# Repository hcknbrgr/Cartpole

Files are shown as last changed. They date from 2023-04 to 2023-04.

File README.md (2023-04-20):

# Cart-pole Deep Q Network Reinforcement Learning
This is my attempt at utilizing a DQN to teach a robot to solve the cart-pole problem.

Original 3d models designed for a pole to be held upright on the cart and balance.  Upon completion of building the model, the wiring would keep the pole balanced on its own and did not allow for any balancing.  I pivoted, manually recreated the model to train to self-balance on its bottom two wheels.

Short video demonstrating the early attempts at training the model:
https://www.youtube.com/watch?v=-TPxhqB77YM

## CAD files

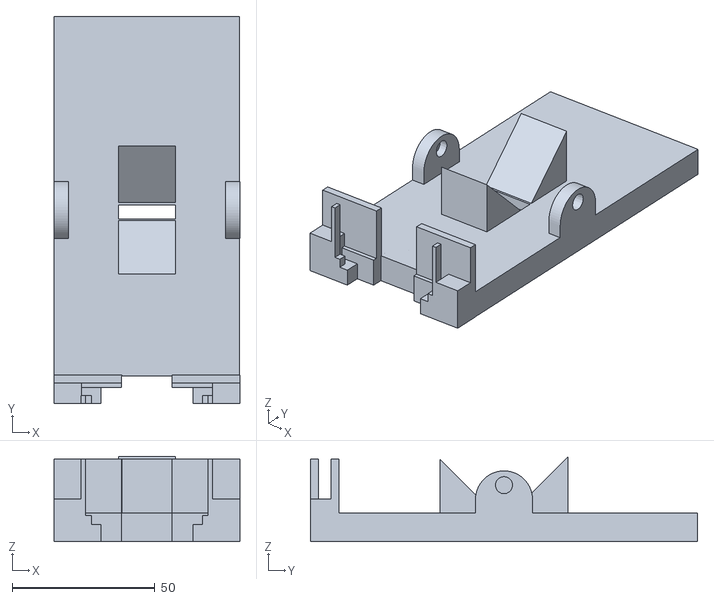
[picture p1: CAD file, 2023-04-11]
3dModels/FullCart0.4 TinkerCAD glitch fix.stl
65.1 x 135.6 x 29.9

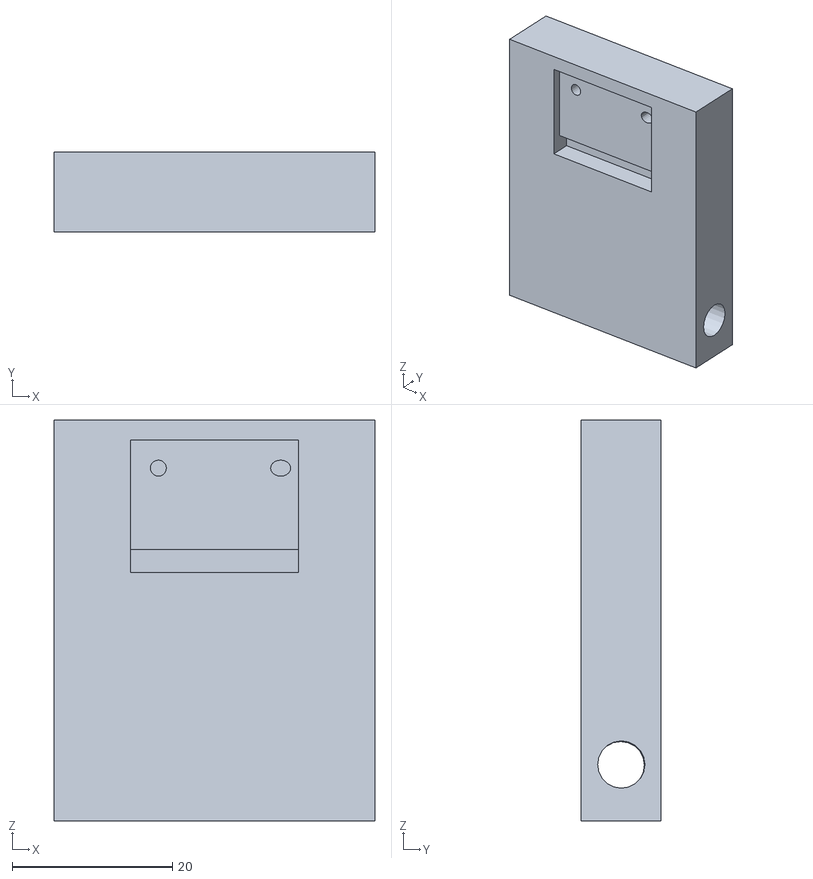
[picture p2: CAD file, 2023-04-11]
3dModels/Pole0.3.stl
40.0 x 10.0 x 50.0

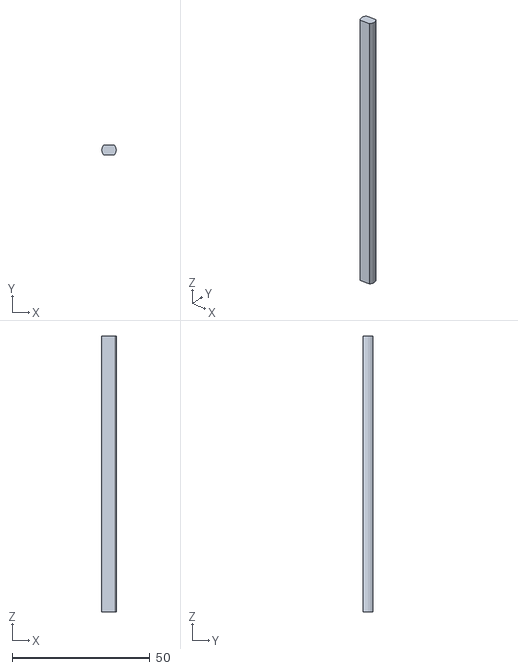
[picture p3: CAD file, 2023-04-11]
3dModels/Axel0.2.stl
5.30 x 3.50 x 100.0

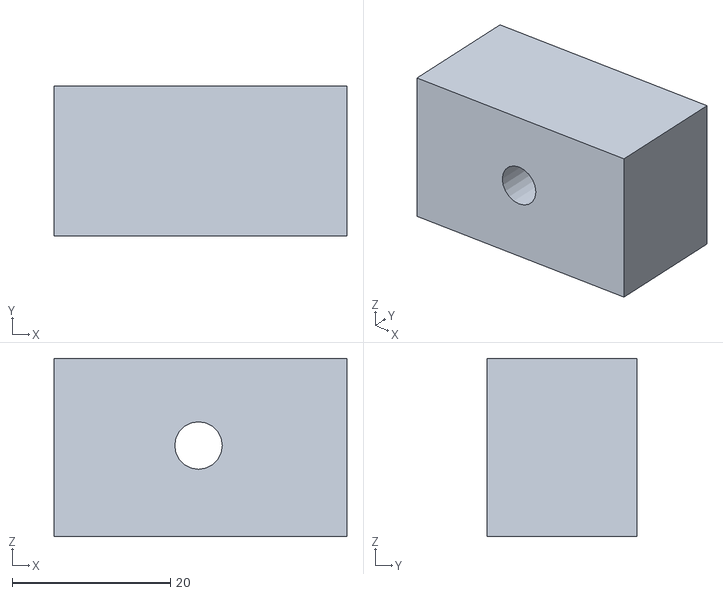
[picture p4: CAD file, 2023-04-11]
3dModels/Wheel Mounts0.2.stl
37.0 x 19.0 x 22.5

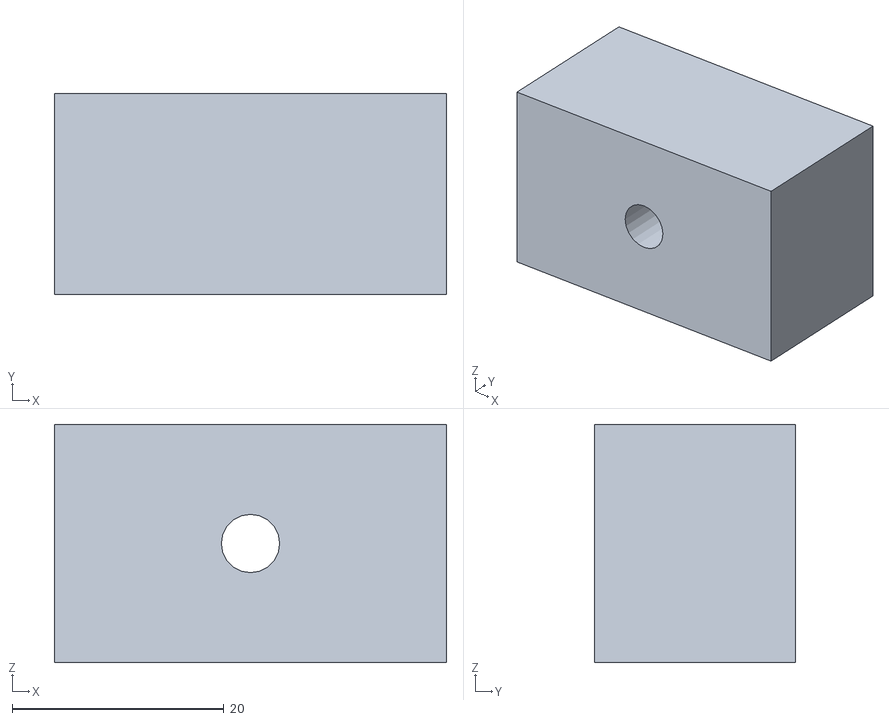
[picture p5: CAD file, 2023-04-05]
3dModels/Wheel Mounts0.1.stl
37.0 x 19.0 x 22.5

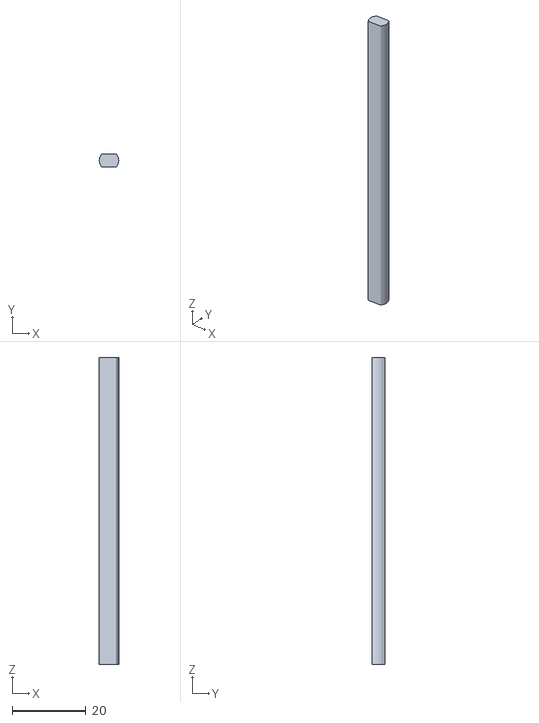
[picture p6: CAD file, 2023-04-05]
3dModels/Axel0.1.stl
5.30 x 3.50 x 83.0

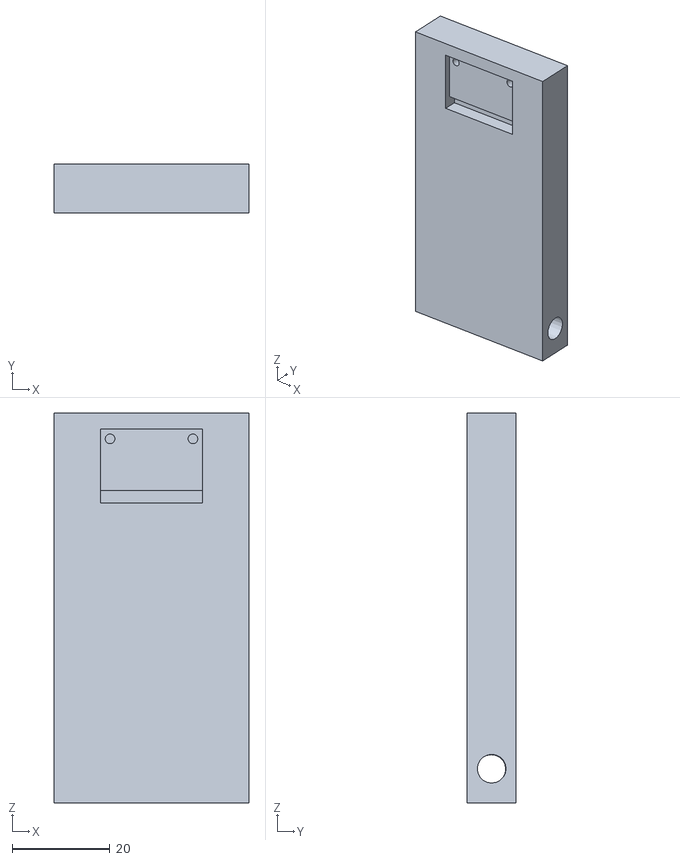
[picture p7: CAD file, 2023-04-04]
3dModels/Pole0.2.stl
40.0 x 10.0 x 80.0

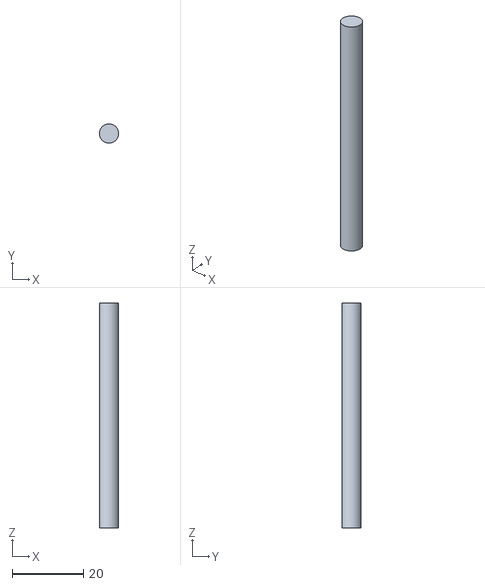
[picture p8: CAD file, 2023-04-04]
3dModels/Stick0.1.stl
5.40 x 5.40 x 63.0

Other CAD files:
3dModels/FullCart0.3.stl
3dModels/FullCart0.2.stl
3dModels/FullCart0.1.stl
3dModels/Pole0.1.stl

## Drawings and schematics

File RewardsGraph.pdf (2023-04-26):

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

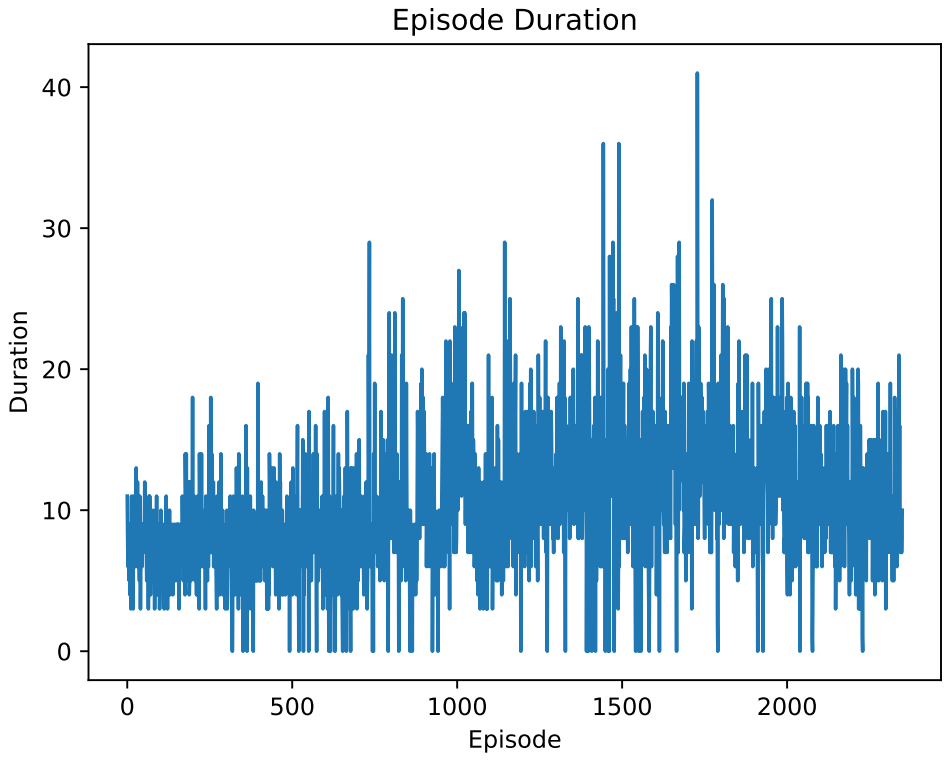
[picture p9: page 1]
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

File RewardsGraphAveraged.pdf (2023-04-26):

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

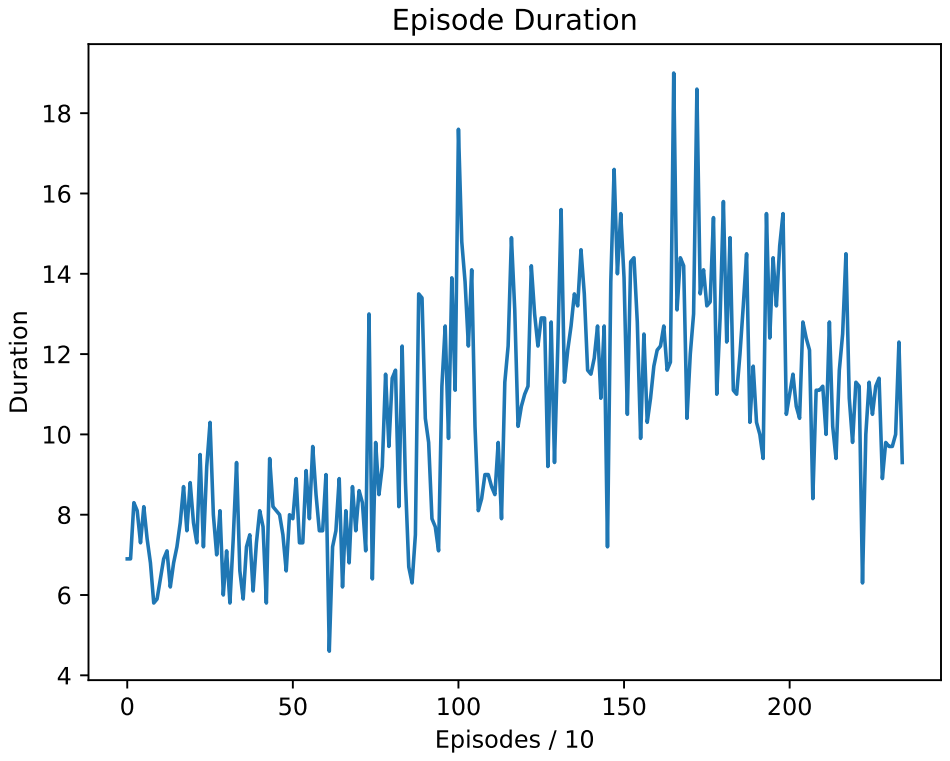
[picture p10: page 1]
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

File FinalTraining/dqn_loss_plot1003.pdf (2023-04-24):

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

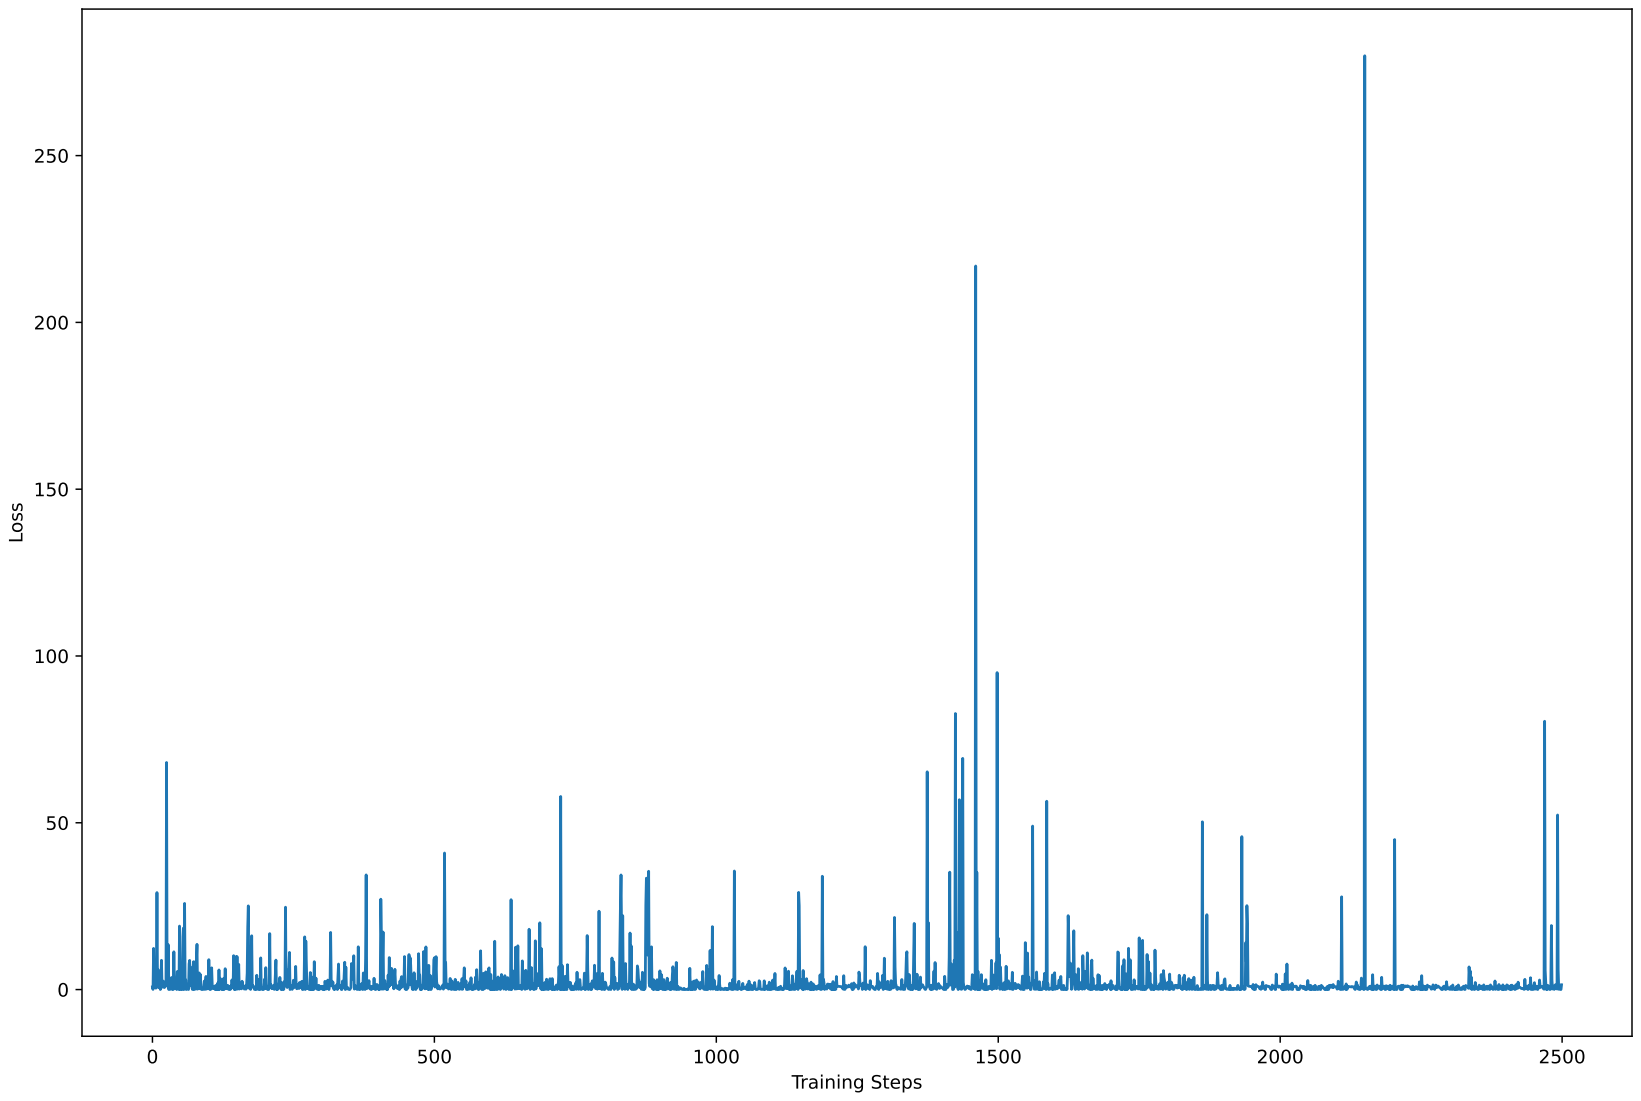
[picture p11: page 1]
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

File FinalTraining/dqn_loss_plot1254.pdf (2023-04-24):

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

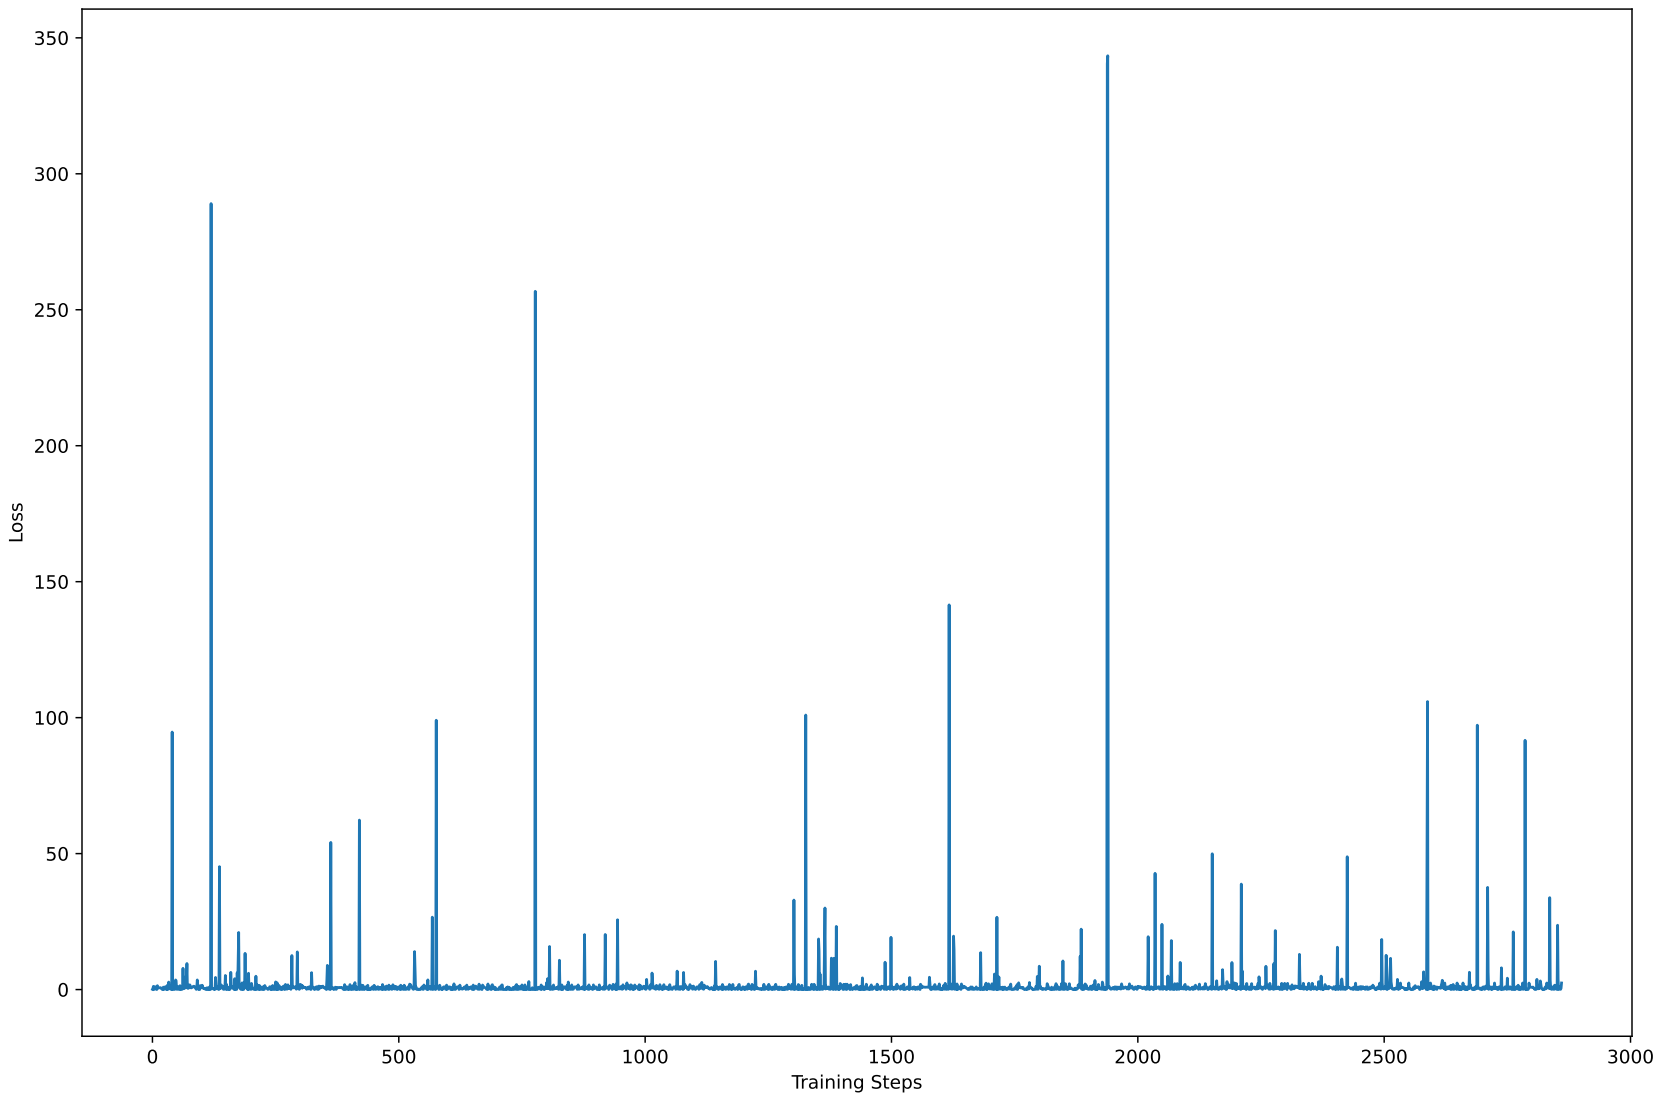
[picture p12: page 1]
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

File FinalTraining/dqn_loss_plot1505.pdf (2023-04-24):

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

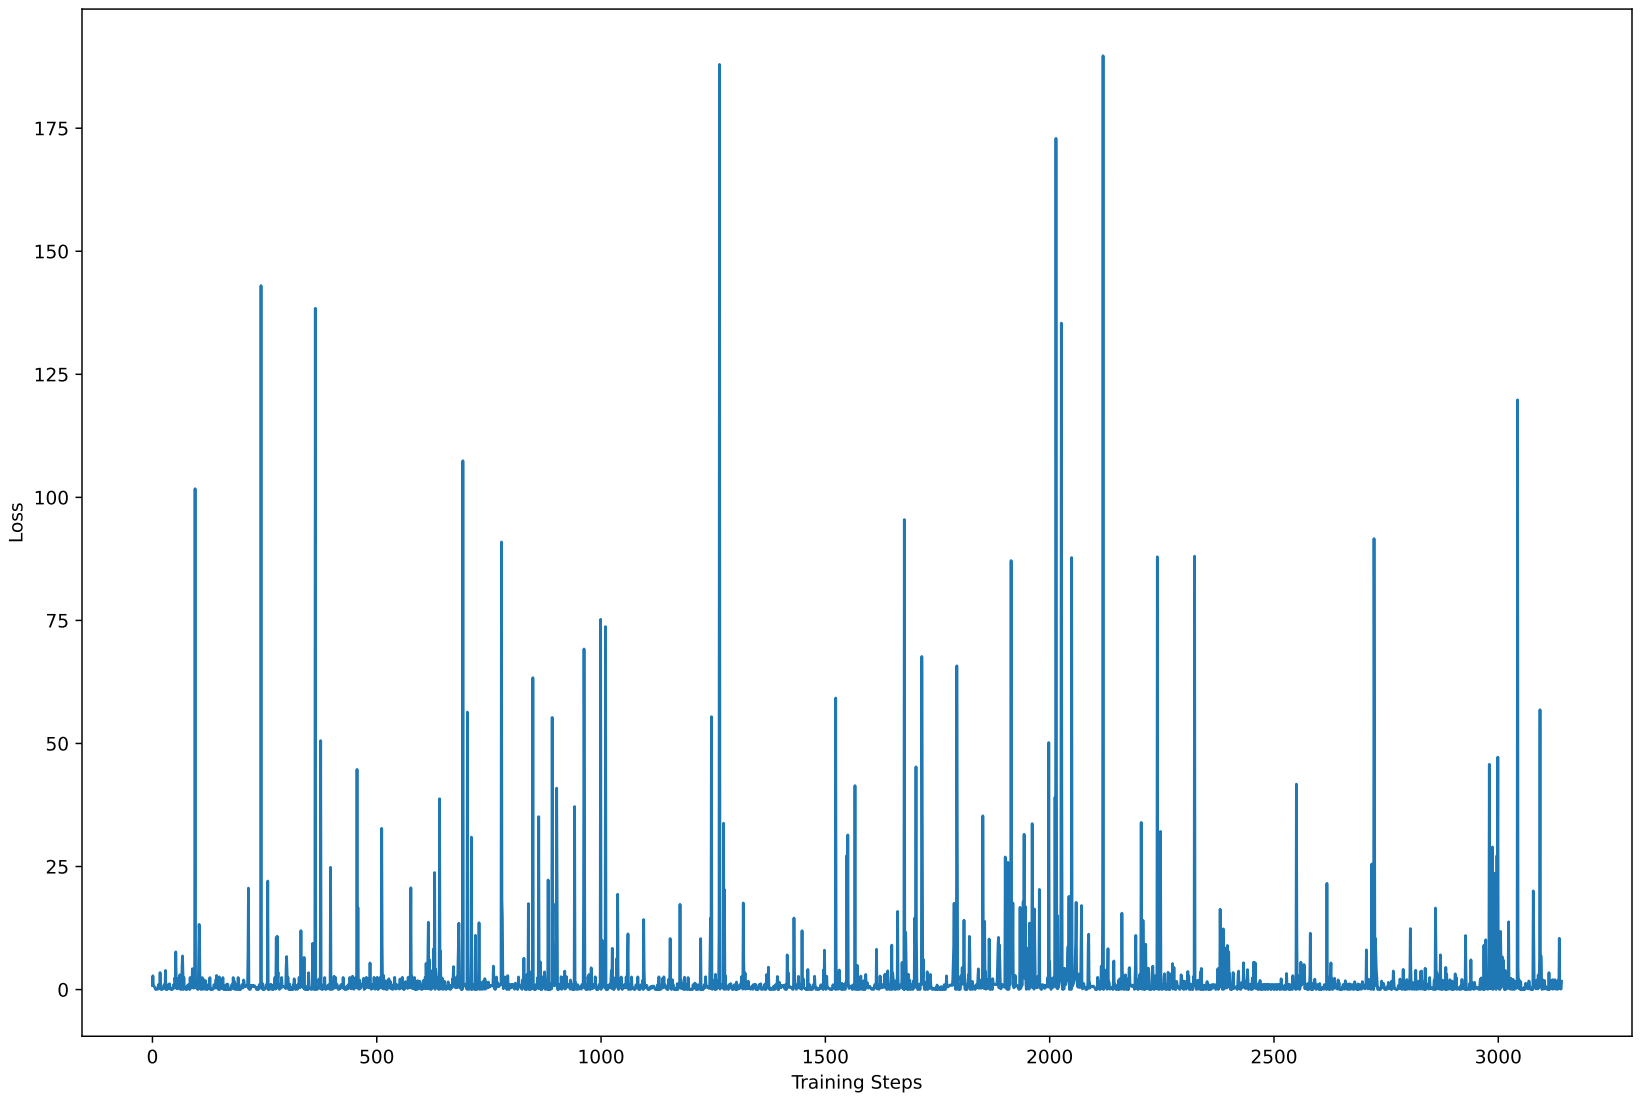
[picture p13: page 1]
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

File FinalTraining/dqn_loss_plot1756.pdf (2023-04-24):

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

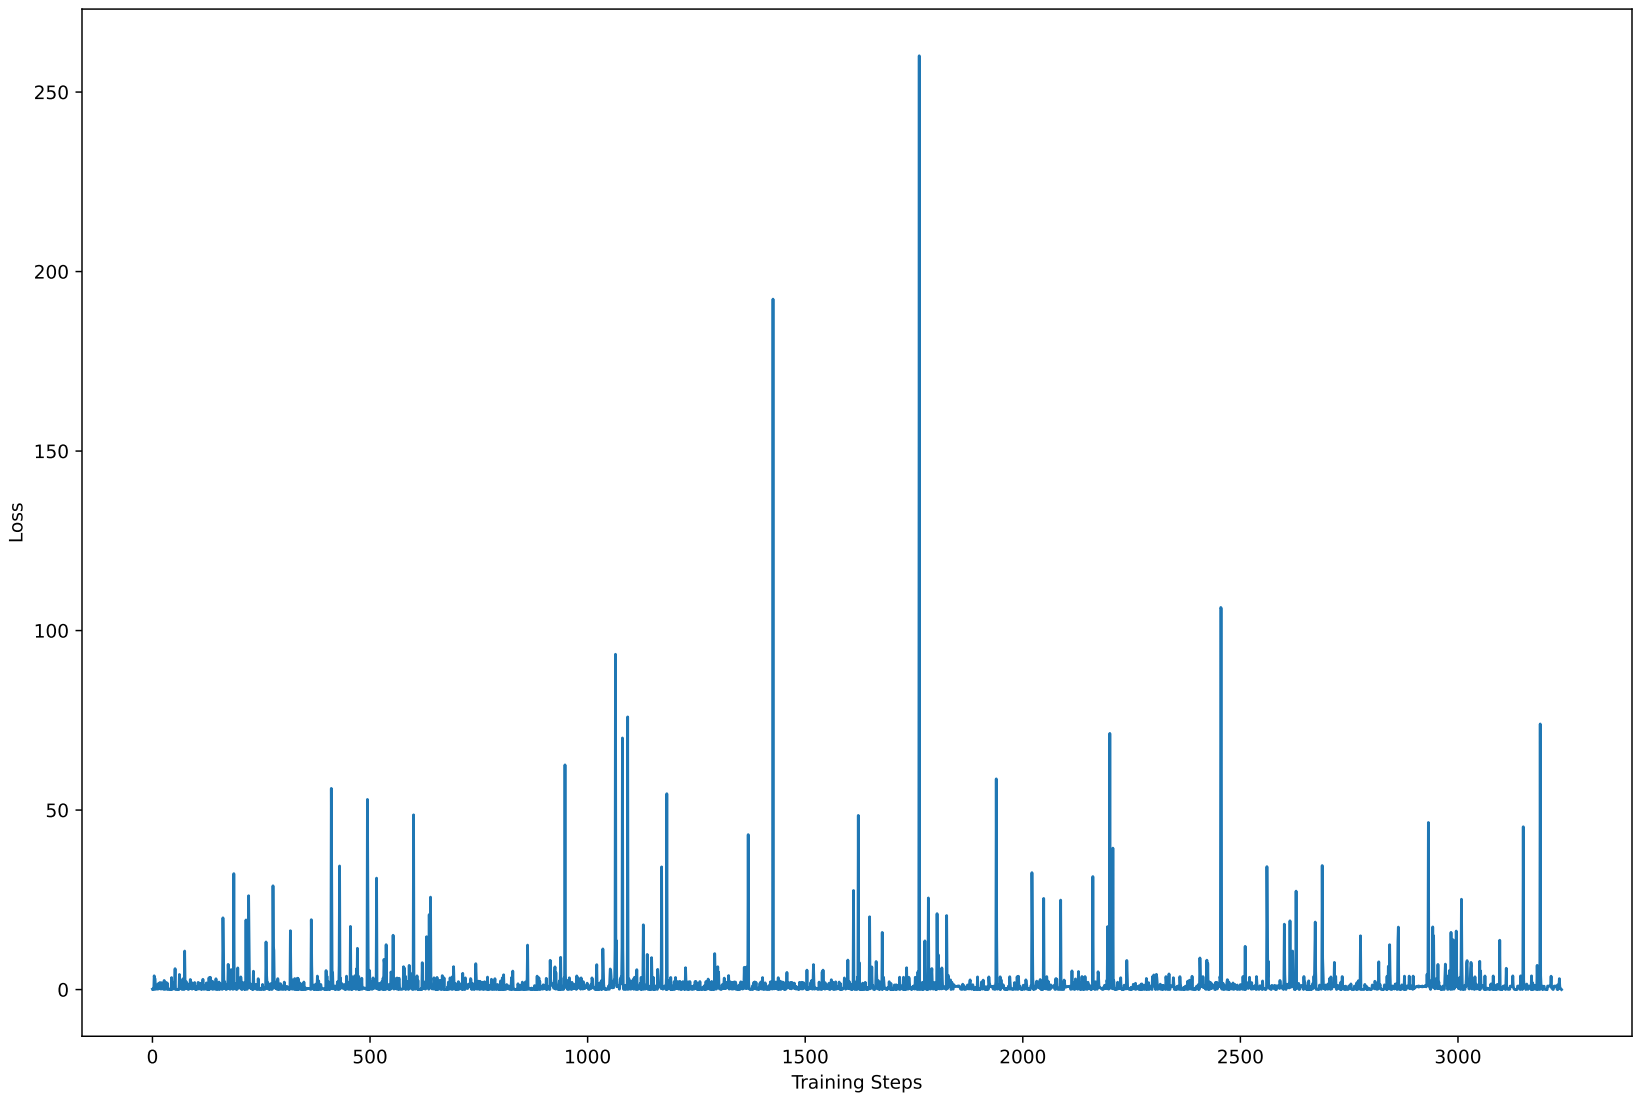
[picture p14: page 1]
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

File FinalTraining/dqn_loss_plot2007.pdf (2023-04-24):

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

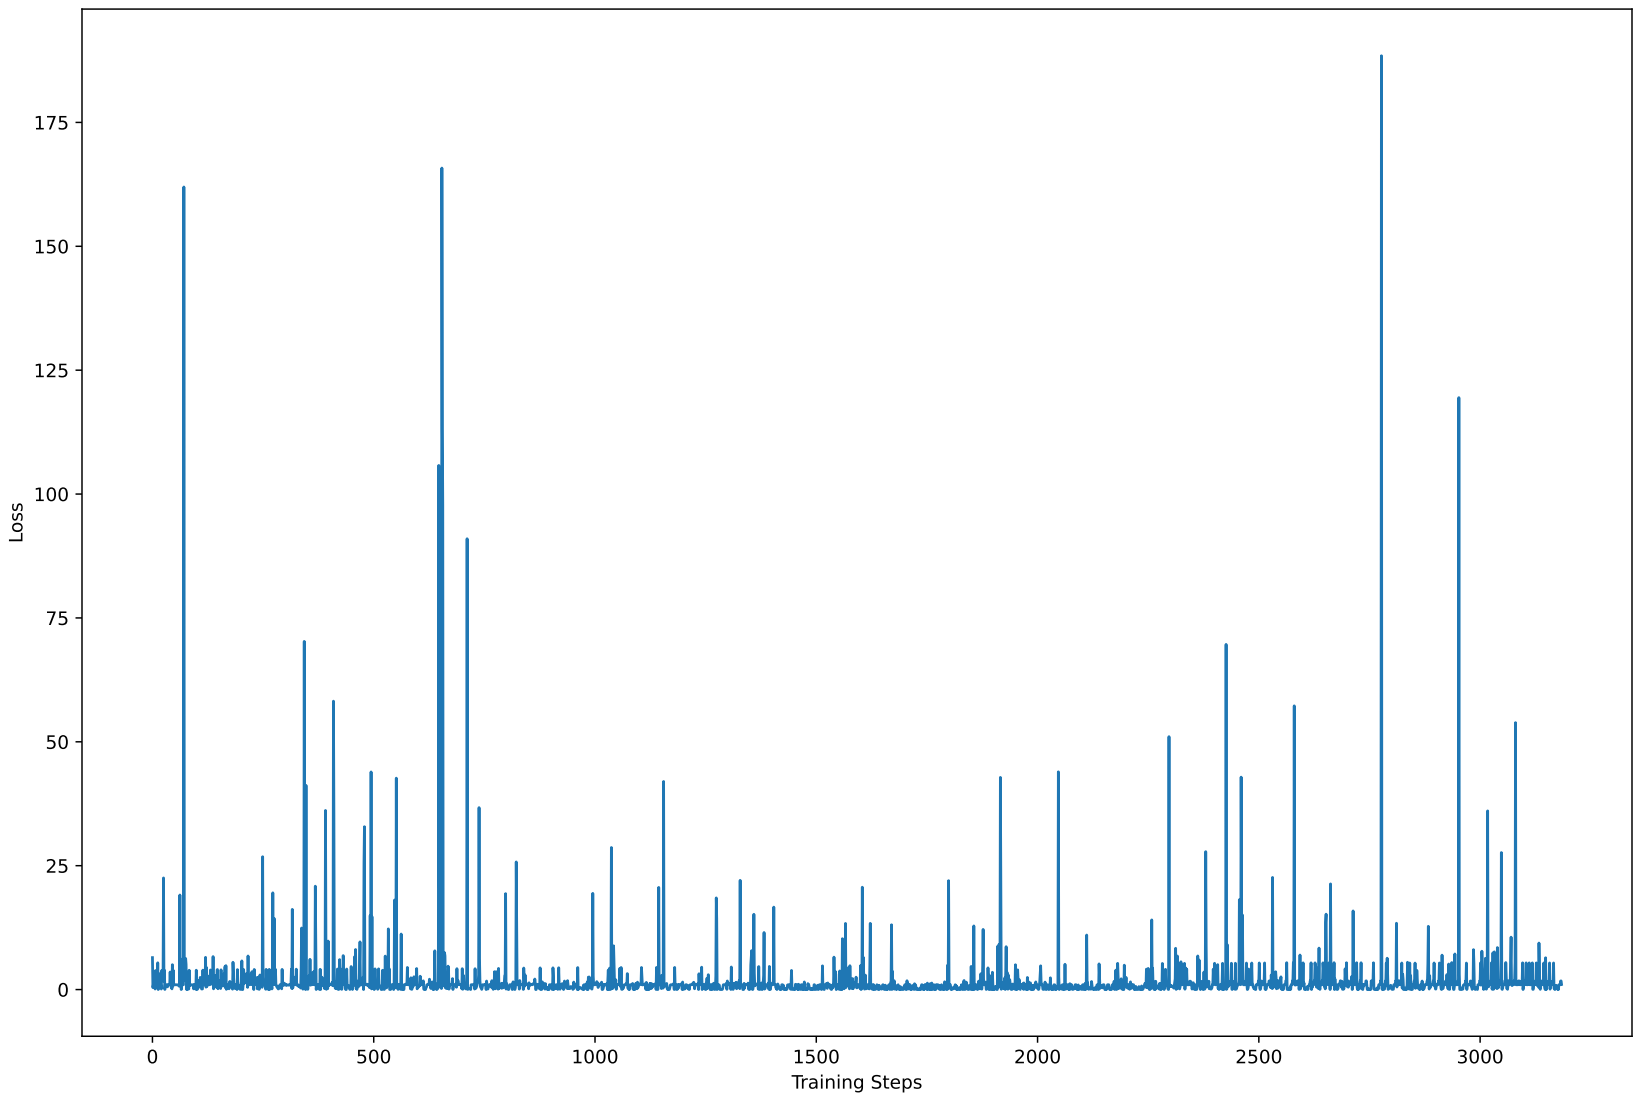
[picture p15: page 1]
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

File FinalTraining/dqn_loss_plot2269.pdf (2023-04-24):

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

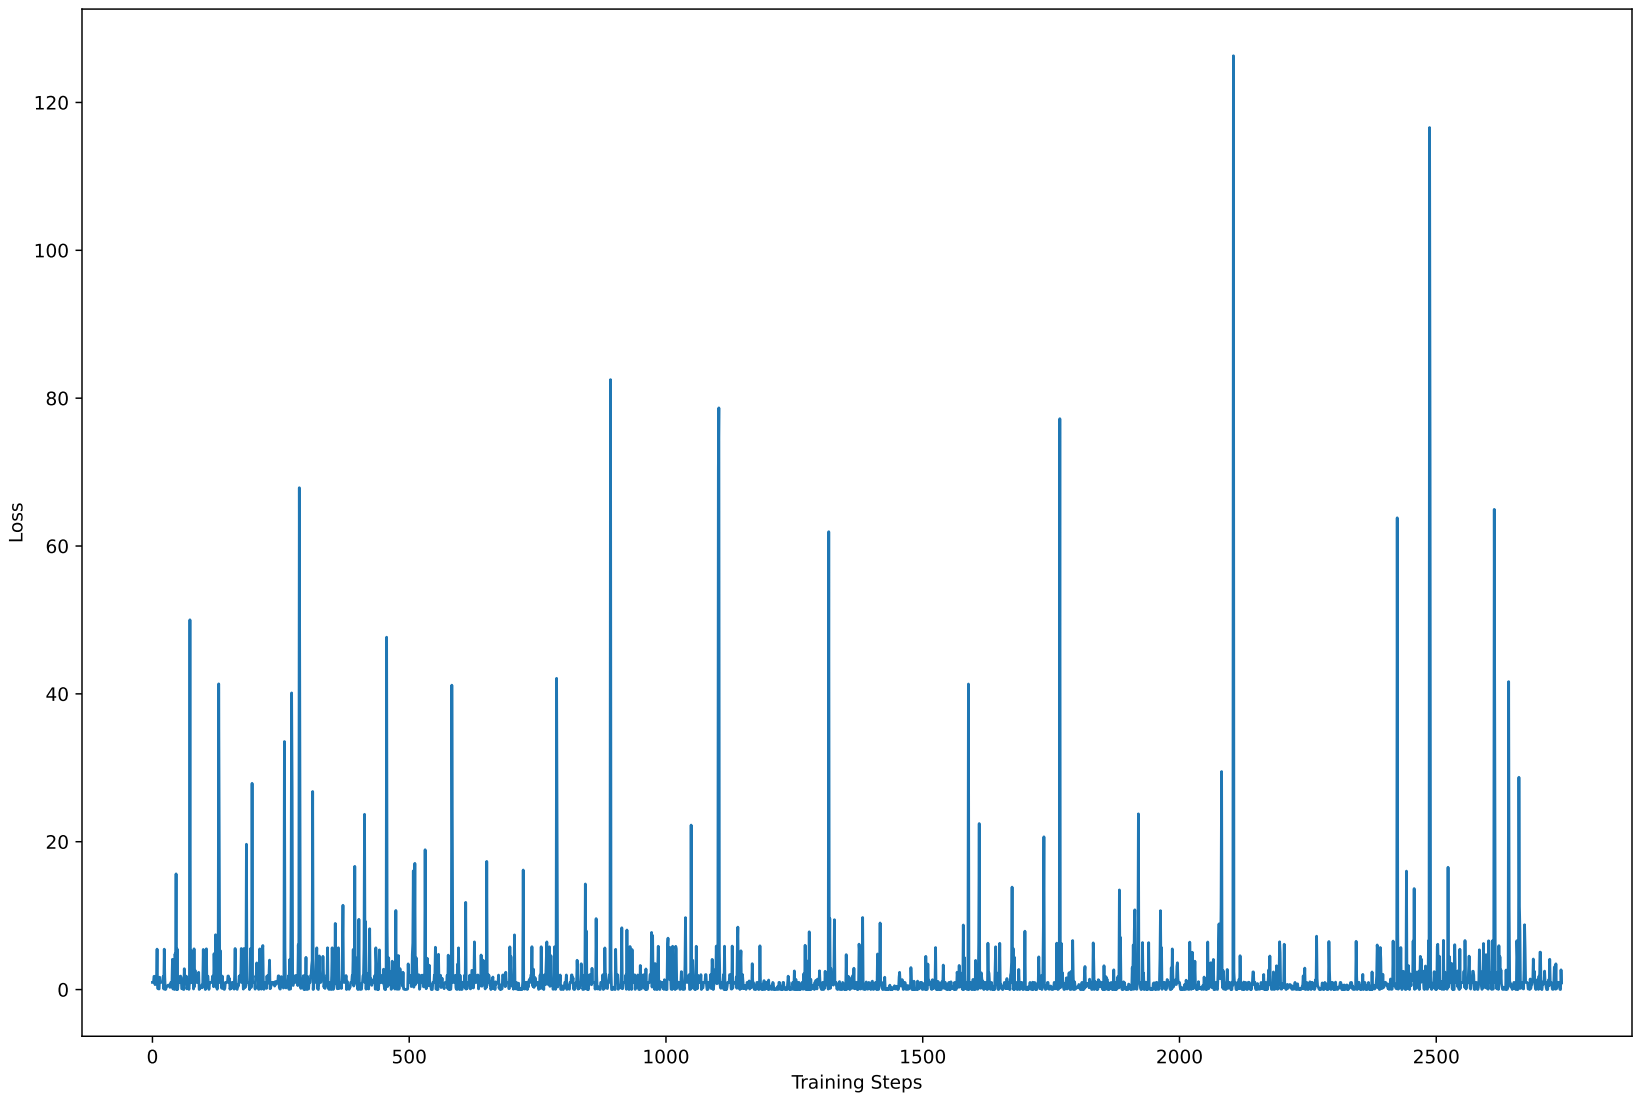
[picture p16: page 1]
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

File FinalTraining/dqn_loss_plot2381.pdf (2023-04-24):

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

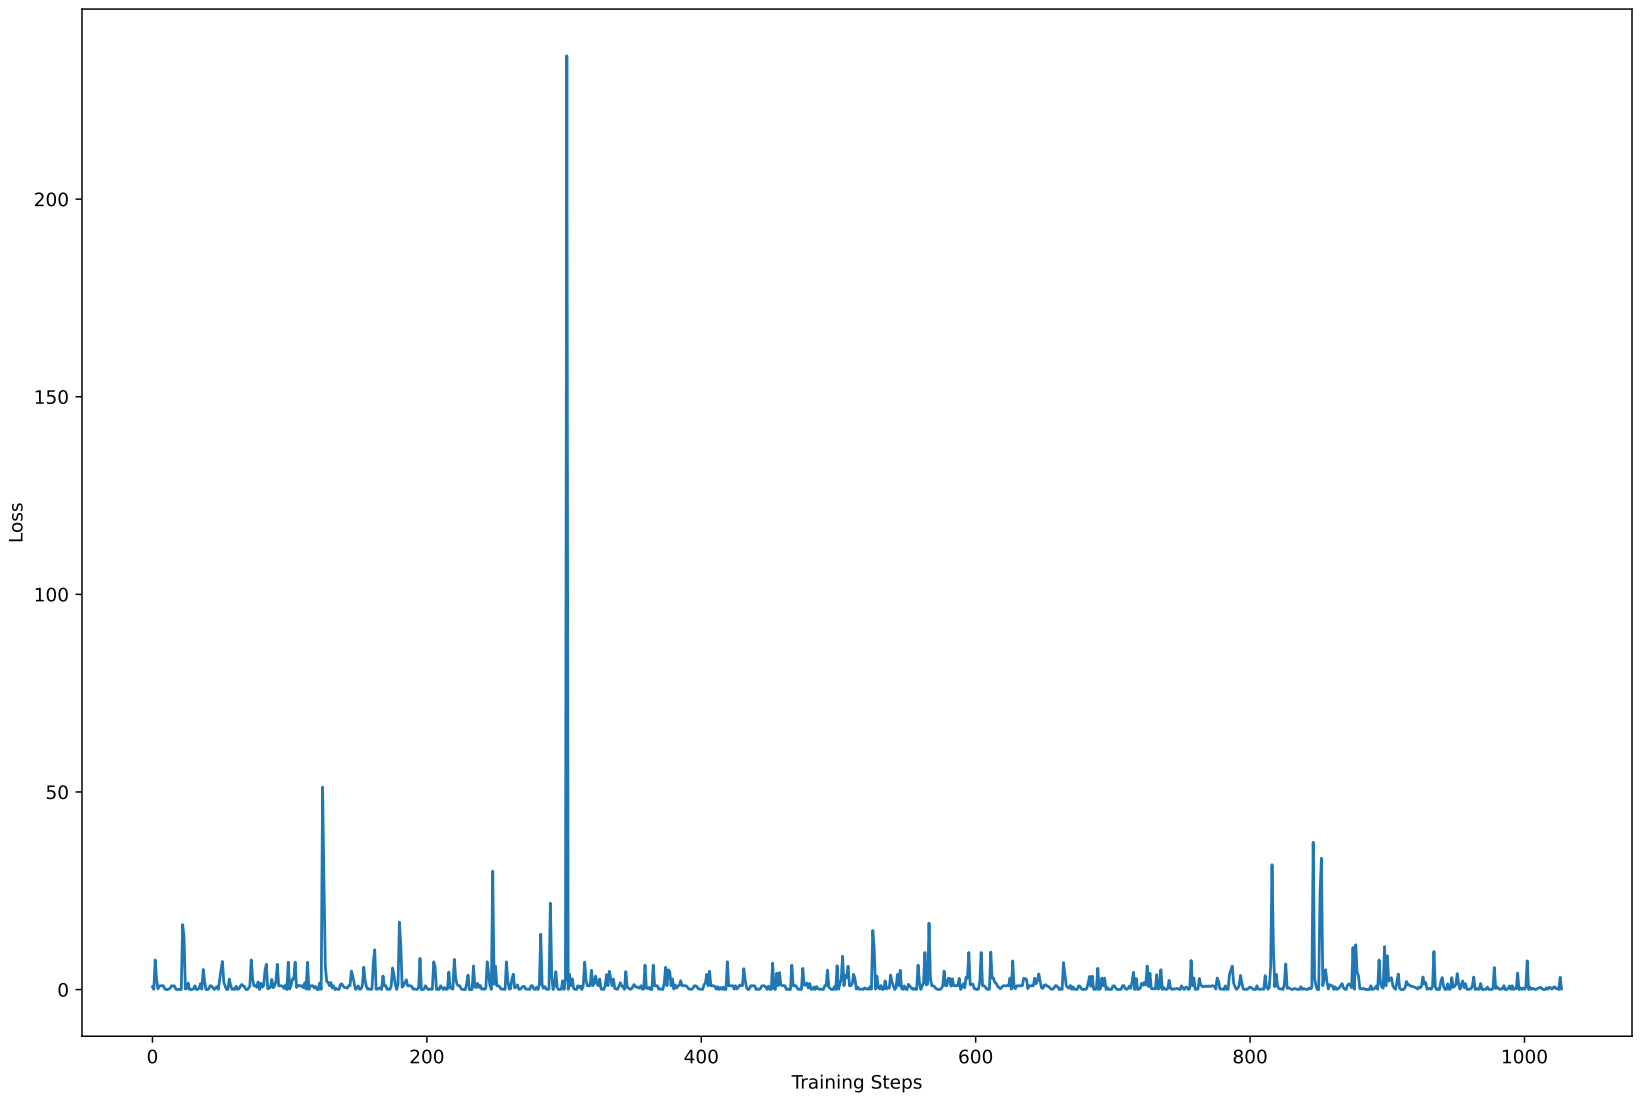
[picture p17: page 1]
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

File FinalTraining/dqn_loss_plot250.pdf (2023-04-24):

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

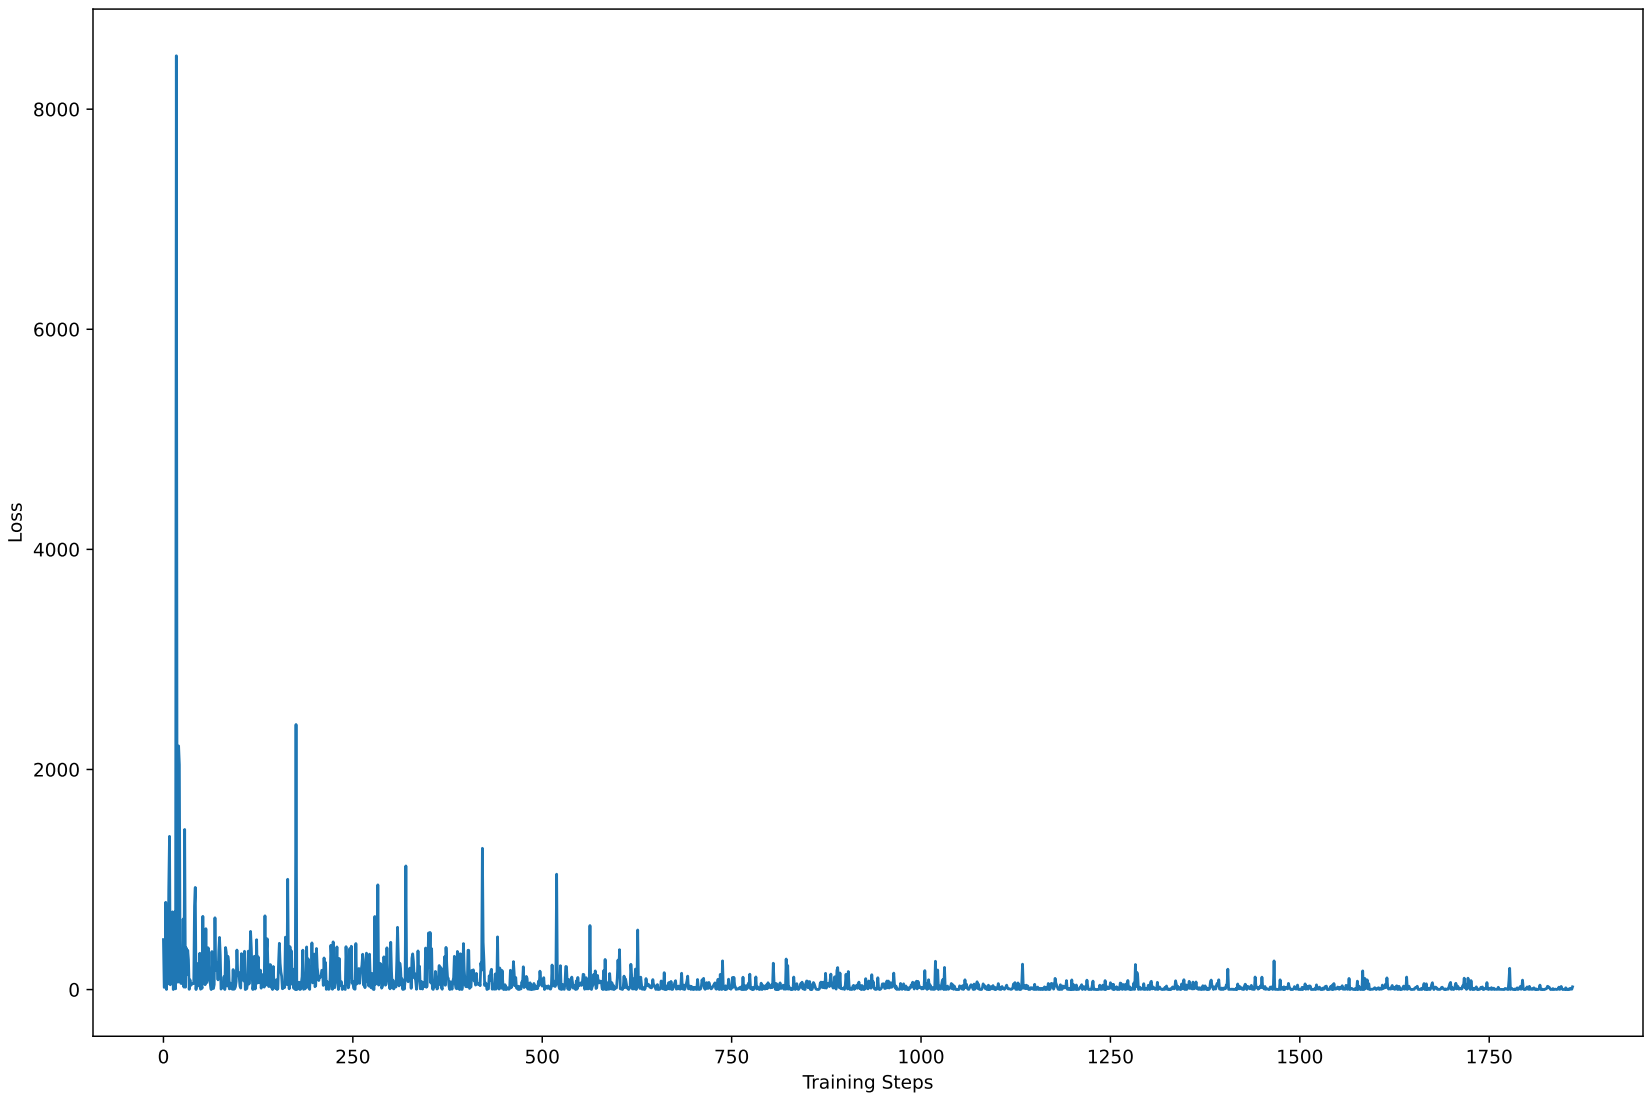
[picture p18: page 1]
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

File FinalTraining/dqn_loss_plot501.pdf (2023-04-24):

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

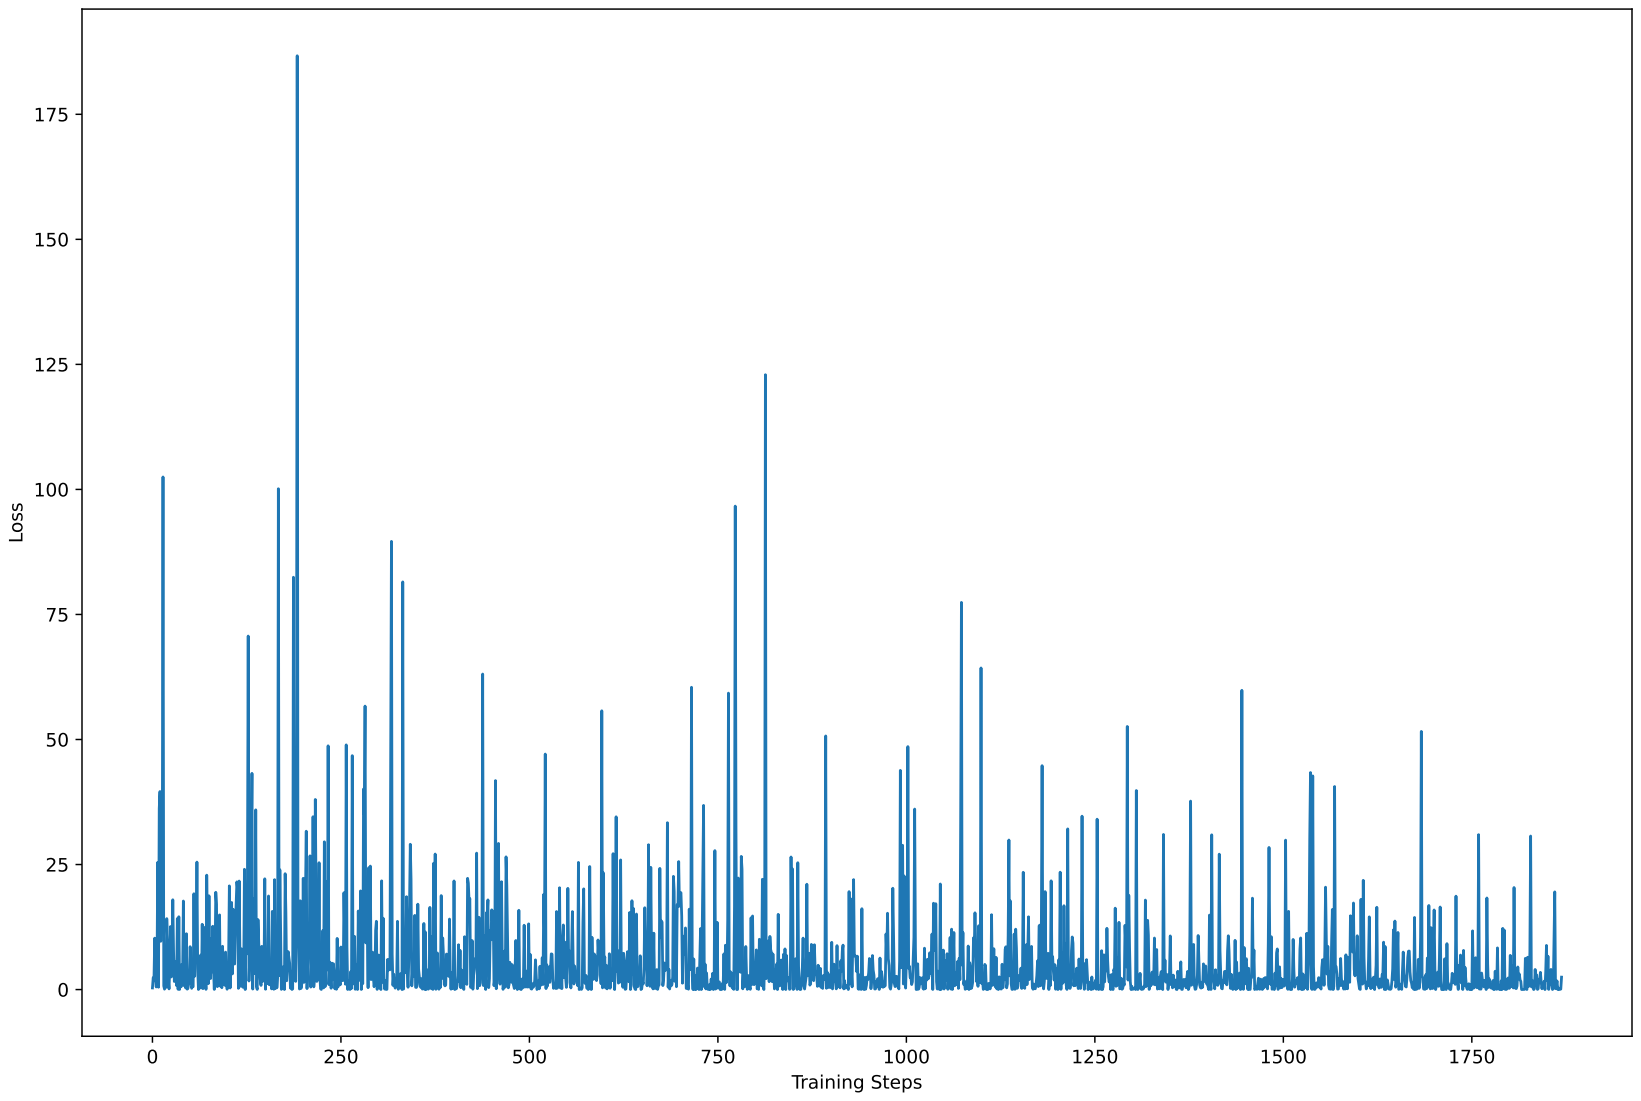
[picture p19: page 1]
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

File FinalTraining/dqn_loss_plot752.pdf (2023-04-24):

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

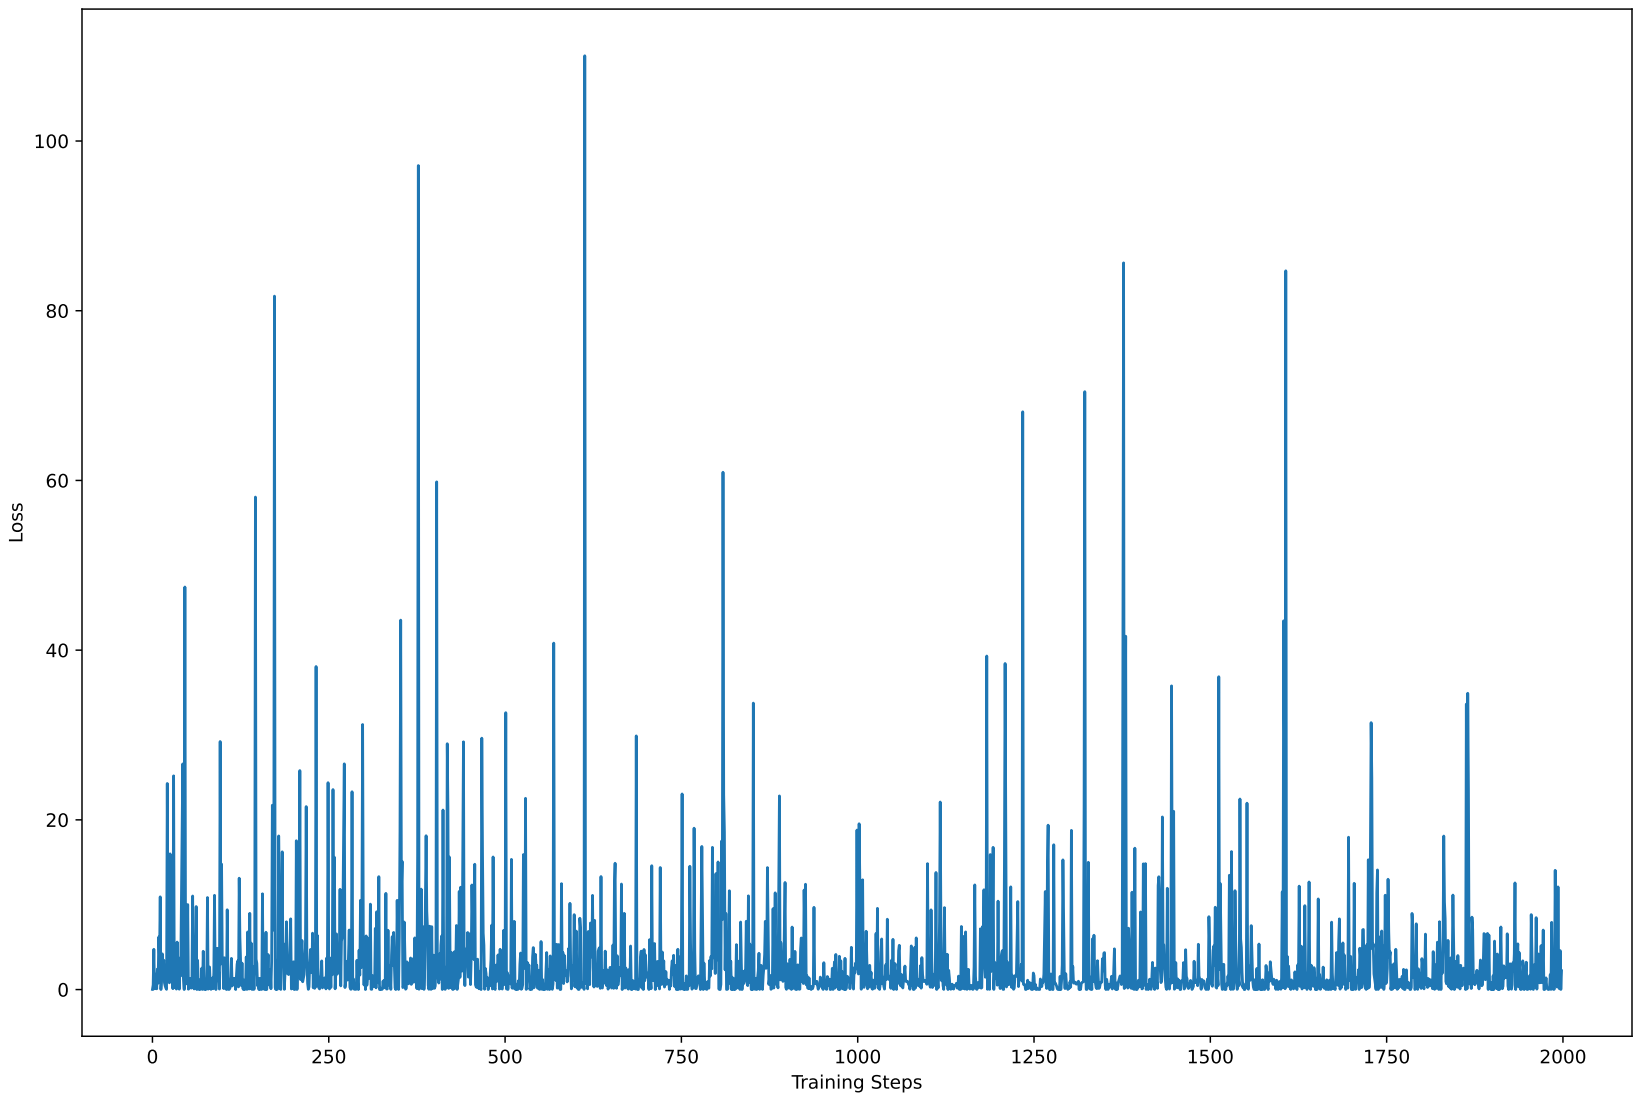
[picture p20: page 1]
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

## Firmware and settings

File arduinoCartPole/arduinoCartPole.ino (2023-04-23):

#include <MPU6050.h>    //Korneliusz Jarzebski’s MPU6050 library from GitHub.
#include <Wire.h>

float testArray[3]= {1.0, 2.0, 3.0};
/*

  On Board LED 
    OnBoardLED: Pin13 - leave this pin empty!!!

  Ultrasonic sensor pins:
    VCC: +5VDC
    Trig : Trigger (Input) - Pin11
    Echo: Echo (OUtput) - Pin12
    GND: GND
  
  MPU 6050 gyroscope pins:
    VCC: +5VDC
    GND: GND
    SCL: SCL
    SDA: SDA

  Motor pinout
    Motor1
      OUT1: Pin1
      OUT2: Pin2
      ENA: PWMPin5
    Motor2
      OUT3: Pin7
      OUT4: Pin8
      ENB: PWMPin10
*/

// MOTOR PINS
int motor1pin1 = 3;
int motor1pin2 = 2;
int motor1PWM = 5;
int motor2pin1 = 7;
int motor2pin2 = 8;
int motor2PWM = 10;
int boardLED = 13;


// ULTRASONIC SENSOR PINS
int trigPin = 11;   // Trigger
int echoPin = 12;   // Echo

MPU6050 mpu;
int initializedCart = 0;   // initialize the distance for the cart
int speed = 0;  // 150 - 255
int motorDirection = 3; // Serial Input to determine which direction to send the motor in. 3 = stationary
int velocity = 0;

void moveCart(int direction)
{
    // 0-2 towards wall 0 - fast, 2 - slow
    // 3 stop
    // 4-6 away from wall, 4 slow, 6 fast
    
    if(direction == 0)  // 0-2 towards wall 0 - fast, 2 - slow
    {
      speed = 250;
      analogWrite(motor1PWM, speed);
      analogWrite(motor2PWM, speed);
      digitalWrite(motor1pin1, HIGH);
      digitalWrite(motor1pin2, LOW);
      digitalWrite(motor2pin1, LOW);
      digitalWrite(motor2pin2, HIGH);
    } 
    else if(direction == 1)  // 0-2 towards wall 0 - fast, 2 - slow
    {
      speed = 200;
      analogWrite(motor1PWM, speed);
      analogWrite(motor2PWM, speed);
      digitalWrite(motor1pin1, HIGH);
      digitalWrite(motor1pin2, LOW);
      digitalWrite(motor2pin1, LOW);
      digitalWrite(motor2pin2, HIGH);
    } 
    else if(direction == 2)  // 0-2 towards wall 0 - fast, 2 - slow
    {
      speed = 150;
      analogWrite(motor1PWM, speed);
      analogWrite(motor2PWM, speed);
      digitalWrite(motor1pin1, HIGH);
      digitalWrite(motor1pin2, LOW);
      digitalWrite(motor2pin1, LOW);
      digitalWrite(motor2pin2, HIGH);
    } 
    else if(direction == 4)  // 4-6 away from wall, 4 slow, 6 fast
    {
      speed = 150;
      analogWrite(motor1PWM, speed);
      analogWrite(motor2PWM, speed);
      digitalWrite(motor1pin1, LOW);
      digitalWrite(motor1pin2, HIGH);
      digitalWrite(motor2pin1, HIGH);
      digitalWrite(motor2pin2, LOW);
    }
    else if(direction == 5)  // 4-6 away from wall, 4 slow, 6 fast
    {
      speed = 200;
      analogWrite(motor1PWM, speed);
      analogWrite(motor2PWM, speed);
      digitalWrite(motor1pin1, LOW);
      digitalWrite(motor1pin2, HIGH);
      digitalWrite(motor2pin1, HIGH);
      digitalWrite(motor2pin2, LOW);
    }
    else if(direction == 6)  // 4-6 away from wall, 4 slow, 6 fast
    {
      speed = 250;
      analogWrite(motor1PWM, speed);
      analogWrite(motor2PWM, speed);
      digitalWrite(motor1pin1, LOW);
      digitalWrite(motor1pin2, HIGH);
      digitalWrite(motor2pin1, HIGH);
      digitalWrite(motor2pin2, LOW);
    }
    else  // 3 = stationary
    {
      speed=0;
      analogWrite(motor1PWM, speed);
      analogWrite(motor2PWM, speed);
      digitalWrite(motor1pin1, LOW);
      digitalWrite(motor1pin2, LOW);
      digitalWrite(motor2pin1, LOW);
      digitalWrite(motor2pin2, LOW);
    }
}  // END MOVE

int verticalInitialization = 0;
long distance = 0;
float poleAngle = 0;
float angularVelocity = 0;
float serialCommunication[4];  //[Cart Position, Cart velocity, Pole Angle, Pole Angular Velocity]

void setup() {
  // Serial Port begin
  Serial.begin(115200); 
  pinMode(boardLED, OUTPUT);
  digitalWrite(boardLED, LOW);  // turn the light off to check the MPU
  while(!mpu.begin(MPU6050_SCALE_2000DPS, MPU6050_RANGE_2G))
  {
    delay(500);
  }
  mpu.calibrateGyro();
  digitalWrite(boardLED, HIGH); // LIGHT TURNS ON AFTER MPU IS ON, THEN YOU CAN RUN PYTHON SCRIPT
  pinMode(trigPin, OUTPUT);
  pinMode(echoPin, INPUT);
  pinMode(motor1pin1, OUTPUT);
  pinMode(motor1pin2, OUTPUT);
  pinMode(motor1PWM, OUTPUT);
  pinMode(motor2pin1, OUTPUT);
  pinMode(motor2pin2, OUTPUT);
  pinMode(motor2PWM, OUTPUT);
  // make sure the motors are off to start
  digitalWrite(motor1pin1, LOW);
  digitalWrite(motor1pin2, LOW);
  digitalWrite(motor2pin1, LOW);
  digitalWrite(motor2pin2, LOW);
}

void loop() {
  // The sensor is triggered by a HIGH pulse of 10 or more microseconds.
  // Give a short LOW pulse beforehand to ensure a clean HIGH pulse;

if(initializedCart == 0)
  {  
    moveCart(3);  // 1 is stop the cart
    digitalWrite(trigPin, LOW);
    delayMicroseconds(5);
    digitalWrite(trigPin, HIGH);
    delayMicroseconds(10);
    digitalWrite(trigPin, LOW);
    pinMode(echoPin, INPUT);
    distance = pulseIn(echoPin, HIGH);
    distance = (distance/2.0) / 29.1;  //int cm = (distance/2) / 29.1;
    Serial.println(distance);  
    Serial.flush();
    while(Serial.available()==0)
    {}
    if(Serial.available()>0) {
      motorDirection = Serial.read(); 
    }
    if(motorDirection == 1)
    {}
    else if(motorDirection == 3)  // 3 = motor pins are already in LOW/LOW, cart is initialized and ready to go
    {
      digitalWrite(boardLED, LOW);  // turn off the light that was turned on when the gyroscope was online
      initializedCart = 1;
      delay(500);
    }
  }  // END CART centered INITIALIZATION
  else if (initializedCart == 1)
  {
    
    Vector normAccel = mpu.readNormalizeAccel();
    poleAngle = (atan2(normAccel.XAxis, normAccel.ZAxis)*180.0)/M_PI;
    Serial.println(poleAngle);   
    Serial.flush();

    while(Serial.available()==0)
    {}

    if(Serial.available()>0) {
      verticalInitialization = Serial.read(); 
    }
    if(verticalInitialization == 0) {}
    else if (verticalInitialization == 1)
    {
      initializedCart = 2;
      digitalWrite(boardLED, HIGH);  // Cart is initialized and ready to go, turn on the board LED!
    }
    
  }
  else if (initializedCart == 2)  // CART IS INITIALIZED,
  {
    // Run the episode.  Send state information, execute action given from NN, repeat until get signal to end
    // The state for each step = [Cart position, cart velocity, pole angle, pole angle velocity]
    digitalWrite(trigPin, LOW);
    delayMicroseconds(5);
    digitalWrite(trigPin, HIGH);
    delayMicroseconds(10);
    digitalWrite(trigPin, LOW);
    pinMode(echoPin, INPUT);
    distance = pulseIn(echoPin, HIGH); // this is the cart position
    distance = (distance/2.0) / 29.1;  //int cm = (distance/2) / 29.1;
    if(motorDirection==0||motorDirection==1||motorDirection==2)
      velocity = -250+(motorDirection)*50;  
    else if(motorDirection==4||motorDirection==5||motorDirection==6)
      velocity = (motorDirection-1)*50;
    else
      velocity = 0;
    Vector normAccel = mpu.readNormalizeAccel();
    poleAngle = (atan2(normAccel.XAxis, normAccel.ZAxis)*180.0)/M_PI;
    Vector normGyro = mpu.readNormalizeGyro();
    angularVelocity=normGyro.YAxis;
    Serial.flush();
    Serial.print(distance);
    Serial.print('/');
    Serial.print(velocity);
    Serial.print('/');
    Serial.print(poleAngle);
    Serial.print('/');
    Serial.println(angularVelocity);
    Serial.flush();

    while(Serial.available()==0)
    {}
    if(Serial.available()>0) {
      motorDirection = Serial.read(); // incoming data = 0 towards wall, 1 away from wall, 2 End of episode
    }
    if(motorDirection == 9)
    {
      initializedCart = 0;
      moveCart(3); // end of episode, halt motor and restart
    }
    else
      moveCart(motorDirection);

  }
  
  delay(50);
  
}

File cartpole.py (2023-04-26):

from os.path import exists
import numpy as np
import torch
import random
from matplotlib import pylab
import serial
import time
import struct  # for sending data as bytes
import csv

# set up neural net
l1 = 4     # Layer 1 -- set up neural net with the number of inputs
l2 = 24    # layers 2 and 3 are hidden layers
l3 = 24
l4 = 7     # 3 speeds to the left,  3 speeds to the right

# set up the neural net
model = torch.nn.Sequential(
    torch.nn.Linear(l1, l2),
    torch.nn.ReLU(),
    torch.nn.Linear(l2, l3),
    torch.nn.ReLU(),
    torch.nn.Linear(l3, l4)
)
loss_fn = torch.nn.MSELoss()
learning_rate = 1e-3
optimizer = torch.optim.Adam(model.parameters(), lr=learning_rate)
epoch_ = 0
episodeRewards = []

if exists('tensor.tar'):
    checkpoint = torch.load('tensor.tar')
    model.load_state_dict(checkpoint['model_state_dict'])
    optimizer.load_state_dict(checkpoint['optimizer_state_dict'])
    epoch_ = checkpoint['epoch']
    loss = checkpoint['loss']
    model.train()

# setup hyperparameters for RL agent
gamma = .99  # discount factor, how much we weight rewards in later states
epsilon = .99   # start with lots of exploration and decay to exploitation
min_epsilon = 0.01
max_time_steps = 250.0
solved_time = 200.0
epsilon_delta = 1.0/1500.0  # linear decay over x iterations...
#print("epsilon delta: ", epsilon_delta)
epsilon = epsilon-epsilon_delta*epoch_  # if we are resuming training, then epsilon needs to resume too
print("starting epsilon: ", epsilon)

# Cart Directions -
# 0 = move towards sensor
# 1 = stationary
# 2 = move away from sensor

# The state for each step = [Cart position, cart "velocity", pole angle, pole angular velocity]

epochs = 250
# how many times we want to train
losses = []   # how well is our neural net doing for each run

# Cart Directions -
# 0-2= move towards sensor
# 3 = stationary
# 4-6 = move away from sensor

# Test the cart distance for initialization.
arduino = serial.Serial('COM7', 115200)  # All communication needs to be blocking for this to work
time.sleep(2)
currentState = []
episodeRewards = []


for epoch in range(epochs):
    epoch_ += 1
    cartCenteredCounts = 0
    poleVerticalCounts = 0
    while cartCenteredCounts != 2:  # INITIALIZE CART POSITION
        line = arduino.readline()
        if line:
            string = line.decode()
            num = int(string)
            print(num)
            if 12.0 <= num <= 20.0:  # CART IS CENTERED, MAKE SURE IT STAYS THERE A FEW SECONDS
                cartCenteredCounts += 1
                if cartCenteredCounts == 2:   # IF IT'S BEEN CENTERED LONG ENOUGH THEN THE SIGNAL THAT IT'S GOOD
                    arduino.write(struct.pack('>B', 3))
                else:
                    arduino.write(struct.pack('>B', 1))
            else:
                arduino.write(struct.pack('B', 1))  # if it's not, send that's it's not...
    #  END CART INITIALIZED POSITION on board LED should turn off
    #  INITIALIZE THE ACCELEROMETER POSITION
    while poleVerticalCounts < 3:
        line = arduino.readline()
        if line:
            string = line.decode()
            num = float(string)
            print(num)
            if 90.1 < num < 93.2:  # if it's vertical then get ready to go
                poleVerticalCounts += 1
                if poleVerticalCounts == 3:
                    arduino.write(struct.pack('>B', 1))  # cart has been vertical for a total of 3 consecutive cycles
                    print("START EPOCH")
                else:
                    arduino.write(struct.pack('>B', 0))
            else:
                arduino.write(struct.pack('>B', 0))
                poleVerticalCounts = 0
    #  CART IS COMPLETELY INITIALIZED, DO AN EPISODE and train the cart!  The on-board LED should turn on.

    timeStep = 0
    line = arduino.readline().strip()  # observation state = (distance, velocity, poleAngle, angularVelocity)
    if line:
        string = line.decode().split('/')
        for a in string:
            currentState.append(float(a))
        state_ = np.array(currentState)
        state1 = torch.from_numpy(state_).float()
        status = 1
        if len(currentState) != 4:
            status = 0
        currentState.clear()
        consecFails = 0
        while status == 1:
            qvals = model(state1)  # get each of the qvals from the neural net
            qvals_ = qvals.data.numpy()  # underscore is denoting changed data
            if random.random() < epsilon:
                action_ = np.random.randint(0, 7)  # 0-2 towards wall, 4-6 away from wall
                print("Explore: ", action_)
            else:
                action_ = np.argmax(qvals_)
                print("Exploit: ", action_)
            arduino.write(struct.pack('>B', action_))  # write the direction to send the cart in
            # wait for updated state
            line = arduino.readline().strip()  # observation state = (distance, velocity, poleAngle, angularVelocity)
            if line:
                string = line.decode().split('/')
                for a in string:
                    currentState.append(float(a))
            if len(currentState) == 4:
                state2_ = np.array(currentState)
                state2 = torch.from_numpy(state2_).float()
                # observation state = (distance, velocity, poleAngle, angularVelocity)
                # check if cart is within acceptable parameters
                if 5.0 < currentState[0] < 30.0 and 61.0 < currentState[2] < 121.0:
                    reward = 1
                    consecFails = 0
                else:
                    print("Failed state: ", currentState)
                    if consecFails == 2:
                        reward = -1
                    else:
                        reward = 0
                        consecFails += 1
                if timeStep > solved_time:
                    reward = 10
                #print("state: ", currentState)
                currentState.clear()
                with torch.no_grad():
                    newQ = model(state2)
                maxQ = torch.max(newQ)
                if reward == 1:  # if we are moving -- this is good
                    Y = reward + (gamma * maxQ)  # estimate for s'
                else:
                    Y = reward

                Y = torch.Tensor([Y]).detach()
                X = qvals.squeeze()[action_]
                loss = loss_fn(X, Y)
                optimizer.zero_grad()  # update NN
                loss.backward()
                losses.append(loss.item())
                optimizer.step()
                state1 = state2
                timeStep += 1
                if reward != 1 and reward != 0:
                    status = 0
            else:  # failsafe in case cable comes uplugged and we need to restart the epoch
                print("Failed to read complete state")
                status = 0
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

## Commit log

2023-04-04 Add files via upload
    Beta 3d models
    [FullCart.stl, Pole.stl, Stick.stl]
2023-04-04 3d Models of the cart/pole, initial test model.
    [FullCart0.1.stl, Pole0.1.stl, Stick0.1.stl]
2023-04-04 Update to cart and pole model.
    [FullCart0.2.stl, Pole0.2.stl]
2023-04-05 Wheel mount and axel for non-powered wheels
    [Axel.stl, Wheel Mounts.stl]
2023-04-11 Updated 3d models for cart/pole
    [Axel0.1.stl, Axel0.2.stl, FullCart0.3.stl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]
2023-04-11 Update for 3d model
    [Axel.stl]
2023-04-11 Arduino library for MPU6050
2023-04-13 all sensors working
2023-04-14 added PWM for motors, updated pitch and angular velocities
2023-04-16 update value bounds for velocity
2023-04-20 updated epsilon decay and velocity calculation
2023-04-23 Removed bucketization, increased motor direction and speed capabilities to 7 options instead of 2.
2023-04-23 Fixed bug serial read inconsistencies and allowed Arduino to be reset to continue training without crashing
    [cartpole.py]
2023-04-24 Training run data of 2350 epochs. plateau at approximately 13 communication cycles
    [RunningLoss.csv, RunningRewards.csv]
2023-04-26 Final project
    [RunningLoss.csv, RunningRewards.csv]
